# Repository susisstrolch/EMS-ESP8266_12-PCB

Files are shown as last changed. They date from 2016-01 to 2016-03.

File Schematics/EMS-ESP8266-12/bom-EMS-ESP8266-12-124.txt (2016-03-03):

Partlist exported from /home/jorschiedt/Development/Heizung/EMS-ESP12/Schematics/EMS-ESP8266-12/EMS-ESP8266-12.sch at 2/8/15 2:24 PM

Part     Value        Device               Package             Description                                                          
C1       220u         CPOL-EUUD-6,3X8,8    UD-6,3X5,8_NICHICON POLARIZED CAPACITOR, European symbol                           
C2       100p         C2.5/2               C2.5-2              CAPACITOR
C3       1n           C2.5/2               C2.5-2              CAPACITOR
C4       820u         CPOL-EUUD-10X10      UD-10X10_NICHICON   POLARIZED CAPACITOR, European symbol                           
C5       68p          C-EU025-050X050      C025-050X050        CAPACITOR, European symbol                                      
C6       820u         CPOL-EUUD-10X10      UD-10X10_NICHICON   POLARIZED CAPACITOR, European symbol                          
C7       1.5n         C2.5/2               C2.5-2              CAPACITOR
C8       10u          C5/11                C5B11               CAPACITOR                                                    
C9       1n           C2.5/2               C2.5-2              CAPACITOR                                                   
C10      10n          C2.5/2               C2.5-2              CAPACITOR
C11      100n         C2.5/2               C2.5-2              CAPACITOR
D1       BAT46        SCHOTTKY-DIODEDO35-7 DO35-7              Schottky Diode                                              
D2       BAT46        SCHOTTKY-DIODEDO35-7 DO35-7              Schottky Diode                                              
D3       BAT46        SCHOTTKY-DIODEDO35-7 DO35-7              Schottky Diode                                              
D4       BAT46        SCHOTTKY-DIODEDO35-7 DO35-7              Schottky Diode                                              
D5       BAT46        SCHOTTKY-DIODEDO35-7 DO35-7              Schottky Diode                                              
D6       1N4148       SCHOTTKY-DIODEDO35-7 DO35-7              Schottky Diode                                              
EMS      691102710002 691102710002         691102710002        WR-TBL Serie 102 - 5.0mm Horizontal Entry Modular with Press
ESP1     ESP-12ESP-12 ESP-12ESP-12         ESP-12              low cost Wifi to Serial Module
EXT.PORT Ext          MA08-2               MA08-2              PIN HEADER                                                  
IC1      LM393N       LM393N               DIL08               COMPARATOR
L1       4.7uH        MICC12               MICC12              INDUCTOR                                                    
L2       4.7uH        MICC12               MICC12              INDUCTOR                                                    
LED1     3mm          LED3MM               LED3MM              LED
MOD1     D24V3F3      D24VXFX              D24VXFX             Step-Down Spannungsregler
PROGRAM  61300611121  61300611121          61300611121         WR-PHD 2.54mm Pin Header, 6 Pin =>Code : Con_BTB_PHD_2.54_1_
R1       4k7          R-EU_0204/7          0204/7              RESISTOR, European symbol
R2       10K          R-EU_0204/7          0204/7              RESISTOR, European symbol
R3       4k7          R-EU_0204/7          0204/7              RESISTOR, European symbol
R4       470R         R-EU_0204/7          0204/7              RESISTOR, European symbol
R5       470R         R-EU_0204/7          0204/7              RESISTOR, European symbol
R6       10K          R-EU_0204/7          0204/7              RESISTOR, European symbol
R7       360R         R-EU_0204/7          0204/7              RESISTOR, European symbol
R8       4K7          R-EU_0204/7          0204/7              RESISTOR, European symbol
R9       47K          R-EU_0204/7          0204/7              RESISTOR, European symbol
R10      10K          R-EU_0204/7          0204/7              RESISTOR, European symbol
R11      100K         R-EU_0204/7          0204/7              RESISTOR, European symbol
R12      4K7          R-EU_0204/7          0204/7              RESISTOR, European symbol
R13      100          R-EU_0204/7          0204/7              RESISTOR, European symbol
SJ1      n.u.         SJ                   SJ                  SMD solder JUMPER
SV1      Mode         MA03-2               MA03-2              PIN HEADER                                                 
T1       BC547B       -NPN-TO92-EBC        TO92-EBC            NPN Transistror
T2       BC547B       -NPN-TO92-EBC        TO92-EBC            NPN Transistror
UPLD     Upload       JP1Q                 JP1                 JUMPER

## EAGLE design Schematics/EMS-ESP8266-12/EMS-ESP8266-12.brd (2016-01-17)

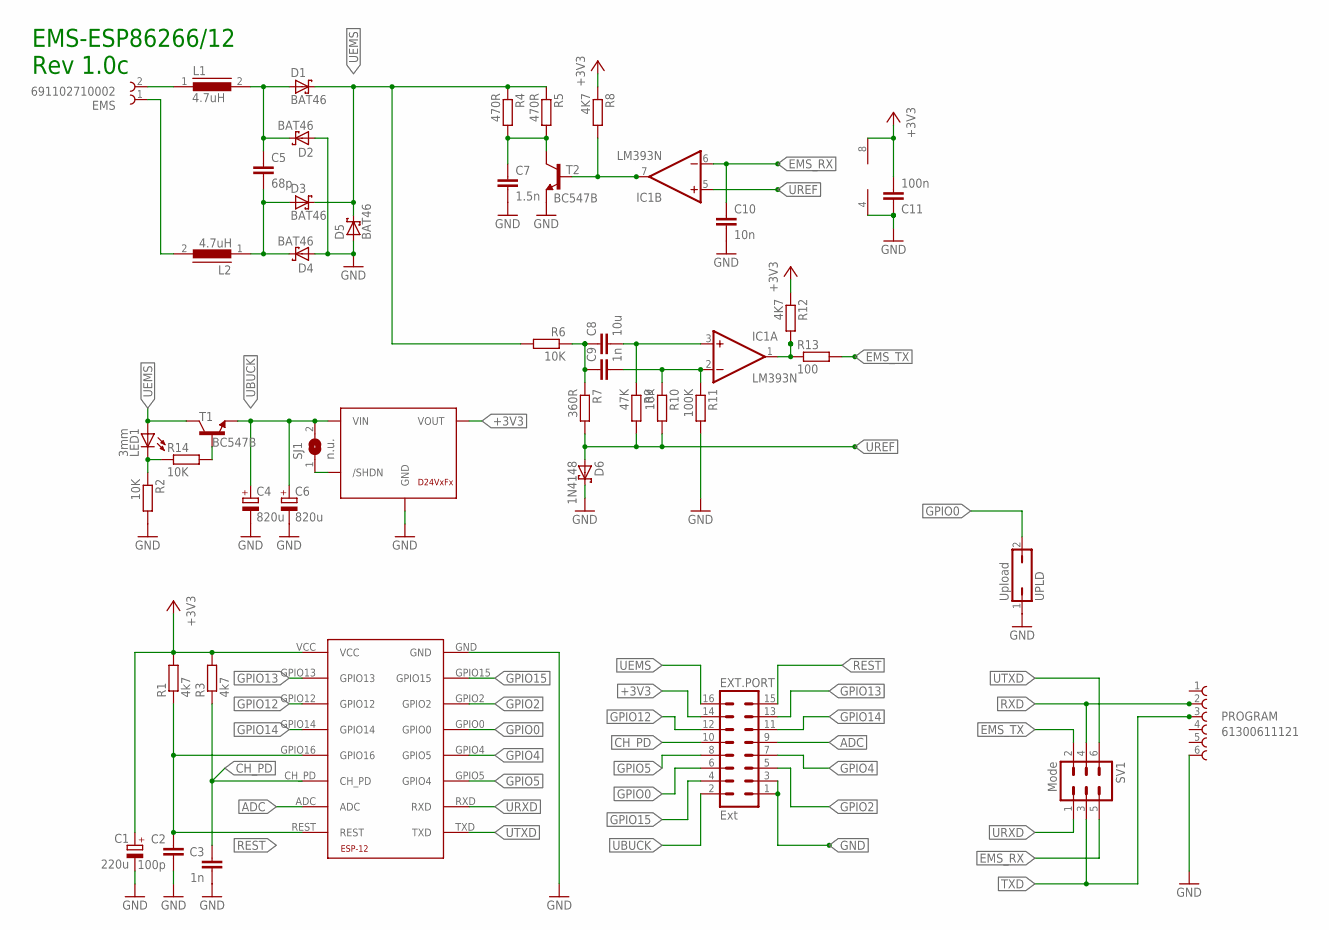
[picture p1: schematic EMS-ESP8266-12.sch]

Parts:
C1: 220u; UD-6,3X5,8_NICHICON
C2: 100p; C2.5-2
C3, C9: 1n; C2.5-2
C4, C6: 820u; UD-10X10_NICHICON
C5: 68p; C025-050X050
C7: 1.5n; C2.5-2
C8: 10u; C5B11
C10: 10n; C2.5-2
C11: 100n; C2.5-2
D1, D2, D3, D4, D5: BAT46; DO35-7
D6: 1N4148; DO35-7
EMS: 691102710002
ESP1: ESP-12ESP-12; ESP-12
EXT.PORT: Ext; MA08-2
IC1: LM393N; DIL08
L1, L2: 4.7uH; MICC12
LED1: 3mm; LED3MM
MOD1: D24V3F3; D24VXFX
PROGRAM: 61300611121
R1, R3: 4k7; 0204/7
R2, R6, R10, R14: 10K; 0204/7
R4, R5: 470R; 0204/7
R7: 360R; 0204/7
R8, R12: 4K7; 0204/7
R9: 47K; 0204/7
R11: 100K; 0204/7
R13: 100; 0204/7
SJ1: n.u.; SJ
SV1: Mode; MA03-2
T1, T2: BC547B; TO92
UPLD: Upload; JP1

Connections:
+3V3: C1.+, C11.2, ESP1.VCC, EXT.PORT.14, IC1.8 (V+), MOD1.VOUT, R1.2, R3.2, R8.1, R12.1
ADC: ESP1.ADC, EXT.PORT.9
CH_PD: C3.1, ESP1.CH_PD, EXT.PORT.10, R3.1
EMS_RX: C10.1, IC1.6 (-IN), SV1.5
EMS_TX: R13.2, SV1.2
GND: C1.-, C2.2, C3.2, C4.-, C6.-, C7.2, C10.2, C11.1, D2.A, D4.A, D5.A, D6.C, ESP1.GND, EXT.PORT.1, EXT.PORT.3, IC1.4 (V-), MOD1.GND, PROGRAM.6, R2.2, R11.2, T2.1 (E), UPLD.1
GPIO0: ESP1.GPIO0, EXT.PORT.6, UPLD.2
GPIO2: ESP1.GPIO2, EXT.PORT.5
GPIO4: ESP1.GPIO4 (GPIO5), EXT.PORT.7
GPIO5: ESP1.GPIO5 (GPIO4), EXT.PORT.8
GPIO12: ESP1.GPIO12, EXT.PORT.12
GPIO13: ESP1.GPIO13, EXT.PORT.13
GPIO14: ESP1.GPIO14, EXT.PORT.11
GPIO15: ESP1.GPIO15, EXT.PORT.4
unnamed: C5.1, D1.A, D2.C, L1.2
unnamed: C5.2, D3.A, D4.C, L2.1
unnamed: MOD1./SHDN, SJ1.1
unnamed: EMS.2, L1.1
unnamed: IC1.1 (OUT), R12.2, R13.1
unnamed: C7.1, R4.2, R5.2, T2.3 (C)
unnamed: C8.1, C9.1, R6.1, R7.1
unnamed: EMS.1, L2.2
unnamed: C8.2, IC1.3 (+IN), R9.1
unnamed: R14.2, T1.2 (B)
unnamed: C9.2, IC1.2 (-IN), R10.1, R11.1
unnamed: IC1.7 (OUT), R8.2, T2.2 (B)
unnamed: LED1.K (C), R2.1, R14.1
REST: C2.1, ESP1.GPIO16, ESP1.REST, EXT.PORT.15, R1.1
RXD: PROGRAM.2, SV1.4
TXD: PROGRAM.3, SV1.3
UBUCK: C4.+, C6.+, EXT.PORT.2, MOD1.VIN, SJ1.2, T1.1 (E)
UEMS: D1.C, D3.C, D5.C, EXT.PORT.16, LED1.A, R4.1, R5.1, R6.2, T1.3 (C)
UREF: D6.A, IC1.5 (+IN), R7.2, R9.2, R10.2
URXD: ESP1.RXD, SV1.1
UTXD: ESP1.TXD, SV1.6

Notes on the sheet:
EMS-ESP86266/12 Rev 1.0c

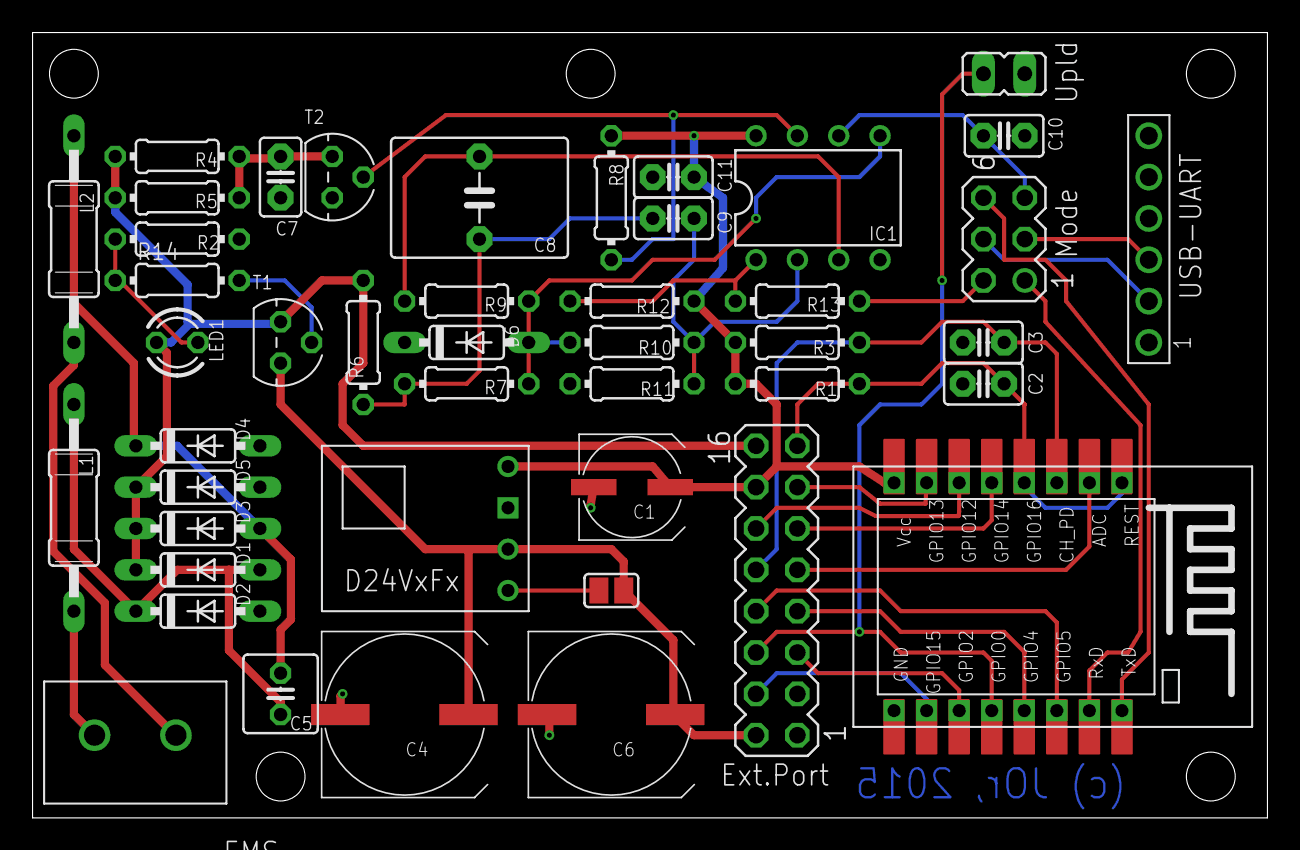
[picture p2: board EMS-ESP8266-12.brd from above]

Board: 2 copper layers, 75.9 x 48.2 mm, 45 parts (0 on the bottom side), 35 nets.

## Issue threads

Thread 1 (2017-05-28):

what kind of hardware is needed?

delchrys, 2017-05-28:
Hello what kind of hardware is needed for this??
I've already made the rx/tx circuit from mikrocontroller.net.
Is it possible to direct put rx/tx from that circuit on the ESP8266??

kind regards,

Bert

susisstrolch, 2018-11-30:
@Bert, sorry - I didn't notice your issue...
If you already have a working converter from ESP to RX/TX, you could use any kind of ESP device - WEMOS or NodeMCU.
You probably have to put a divider network between the converters TX and the ESP RX input to reduce the input voltage to 3,3V max.

Closed 2018-11-30.

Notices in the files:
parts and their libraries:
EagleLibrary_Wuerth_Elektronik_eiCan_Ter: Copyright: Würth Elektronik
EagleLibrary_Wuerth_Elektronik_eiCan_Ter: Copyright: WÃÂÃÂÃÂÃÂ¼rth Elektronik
